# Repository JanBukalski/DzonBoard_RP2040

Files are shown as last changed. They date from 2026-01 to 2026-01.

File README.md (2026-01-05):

# DzonBoard

MCU based on RP2040 microcontroller.
Pin Layout is Equal to Raspberry Pi Pico Pin Layout.

# Why devboard

I made it becouse i think it is fun. And i wanted to learn KiCad.

Now i made working PCB. Before i had 40 errors and now i have 0 :)

# Pictures

Pictures are in pics/ folder.
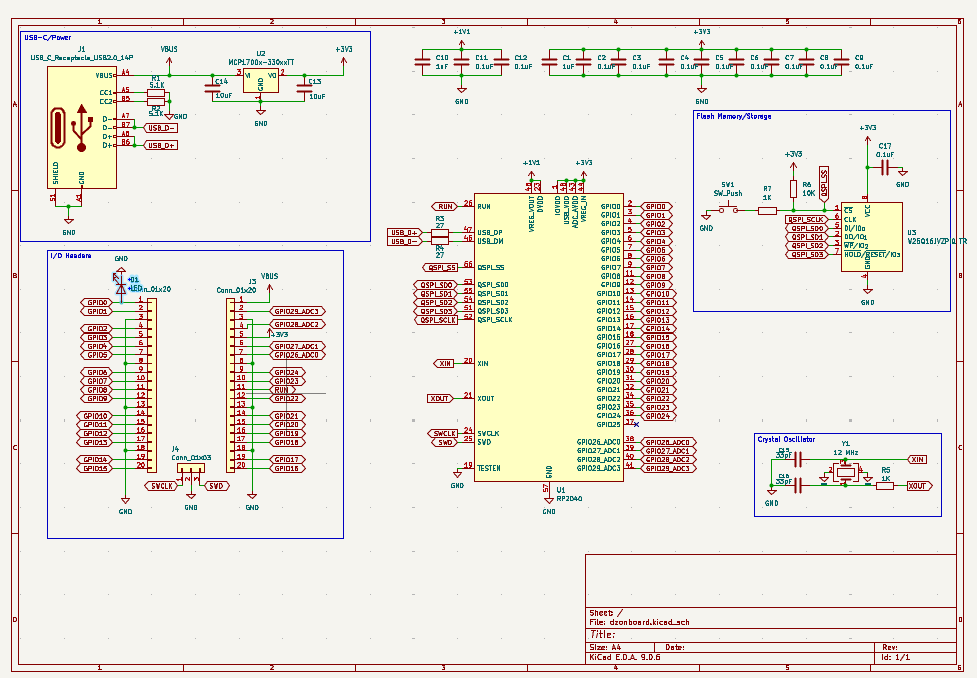
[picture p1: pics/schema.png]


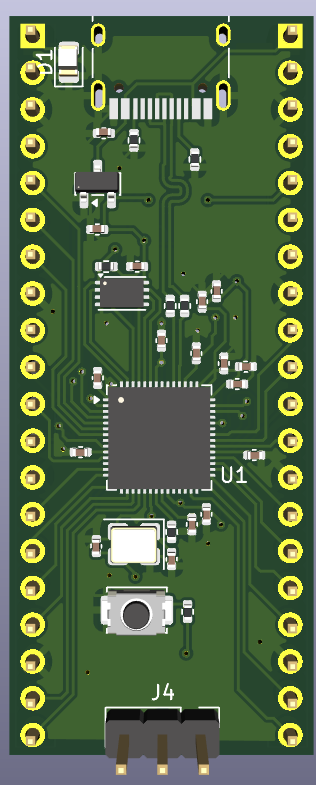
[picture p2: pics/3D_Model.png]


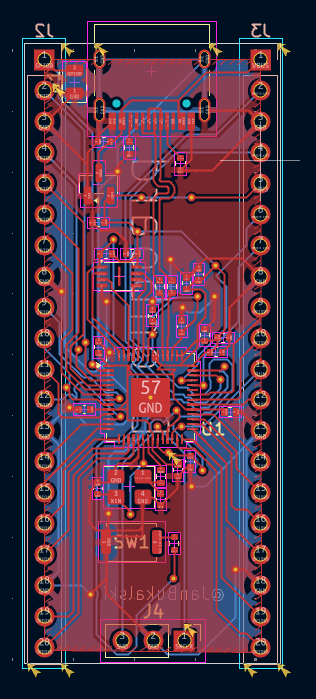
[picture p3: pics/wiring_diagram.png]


# BOM

BOM is in bom.csv file

# Example software

Example firmware is in examples/ folder..

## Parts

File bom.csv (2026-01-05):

Designator | Footprint | Quantity | Value | LCSC Part # | Total price
C1, C10 | 0402 | 2 | 1uF | C15525 | $0.0060
C11, C12, C17, C2, C3, C4, C5, C6, C7, C8, C9 | 0402 | 11 | 0.1uF | C1525 | $0.0132
C13, C14 | 0402 | 2 | 10uF | C15533 | $0.0088
C15, C16 | 0402 | 2 | 33pF | C15515 | $0.0022
D1 | 0805 | 1 | LED | C2290 | $0.0121
J1 | USB_C_Receptacle_HRO_TYPE-C-31-M-12 | 1 | USB_C_Receptacle_USB2.0_14P | C165948 | $0.1764
J2, J3 | PinHeader_1x20_P2.54mm_Vertical | 2 | Conn_01x20 | C124356 | Buying in diffrent shop
J4 | PinHeader_1x03_P2.54mm_Vertical | 1 | Conn_01x03 | C30030 | Buying in diffrent shop
R1, R2 | 0402 | 2 | 5.1K | C25124 | $0.0012
R3, R4 | 0402 | 2 | 27 | C25089 | $0.0012
R5, R7 | 0402 | 2 | 1K | C21190 | $0.0443
R6 | 0402 | 1 | 10K | C25744 | $0.0006
SW1 | SW_Push_SPST_NO_Alps_SKRK | 1 | SW_Push | C13974 | $0.0678
U1 | QFN-56-1EP_7x7mm_P0.4mm_EP3.2x3.2mm | 1 | RP2040 | C2040 | $0.9545
U2 | SOT-23 | 1 | MCP1700x-330xxTT | C13456 | $0.0443
U3 | Winbond_USON-8-1EP_3x2mm_P0.5mm_EP0.2x1.6mm | 1 | W25Q16JVZPIQ TR | C20123 | $0.9358
Y1 | Crystal_SMD_3225-4Pin_3.2x2.5mm | 1 | 12 MHz | C12345 | $0.0242

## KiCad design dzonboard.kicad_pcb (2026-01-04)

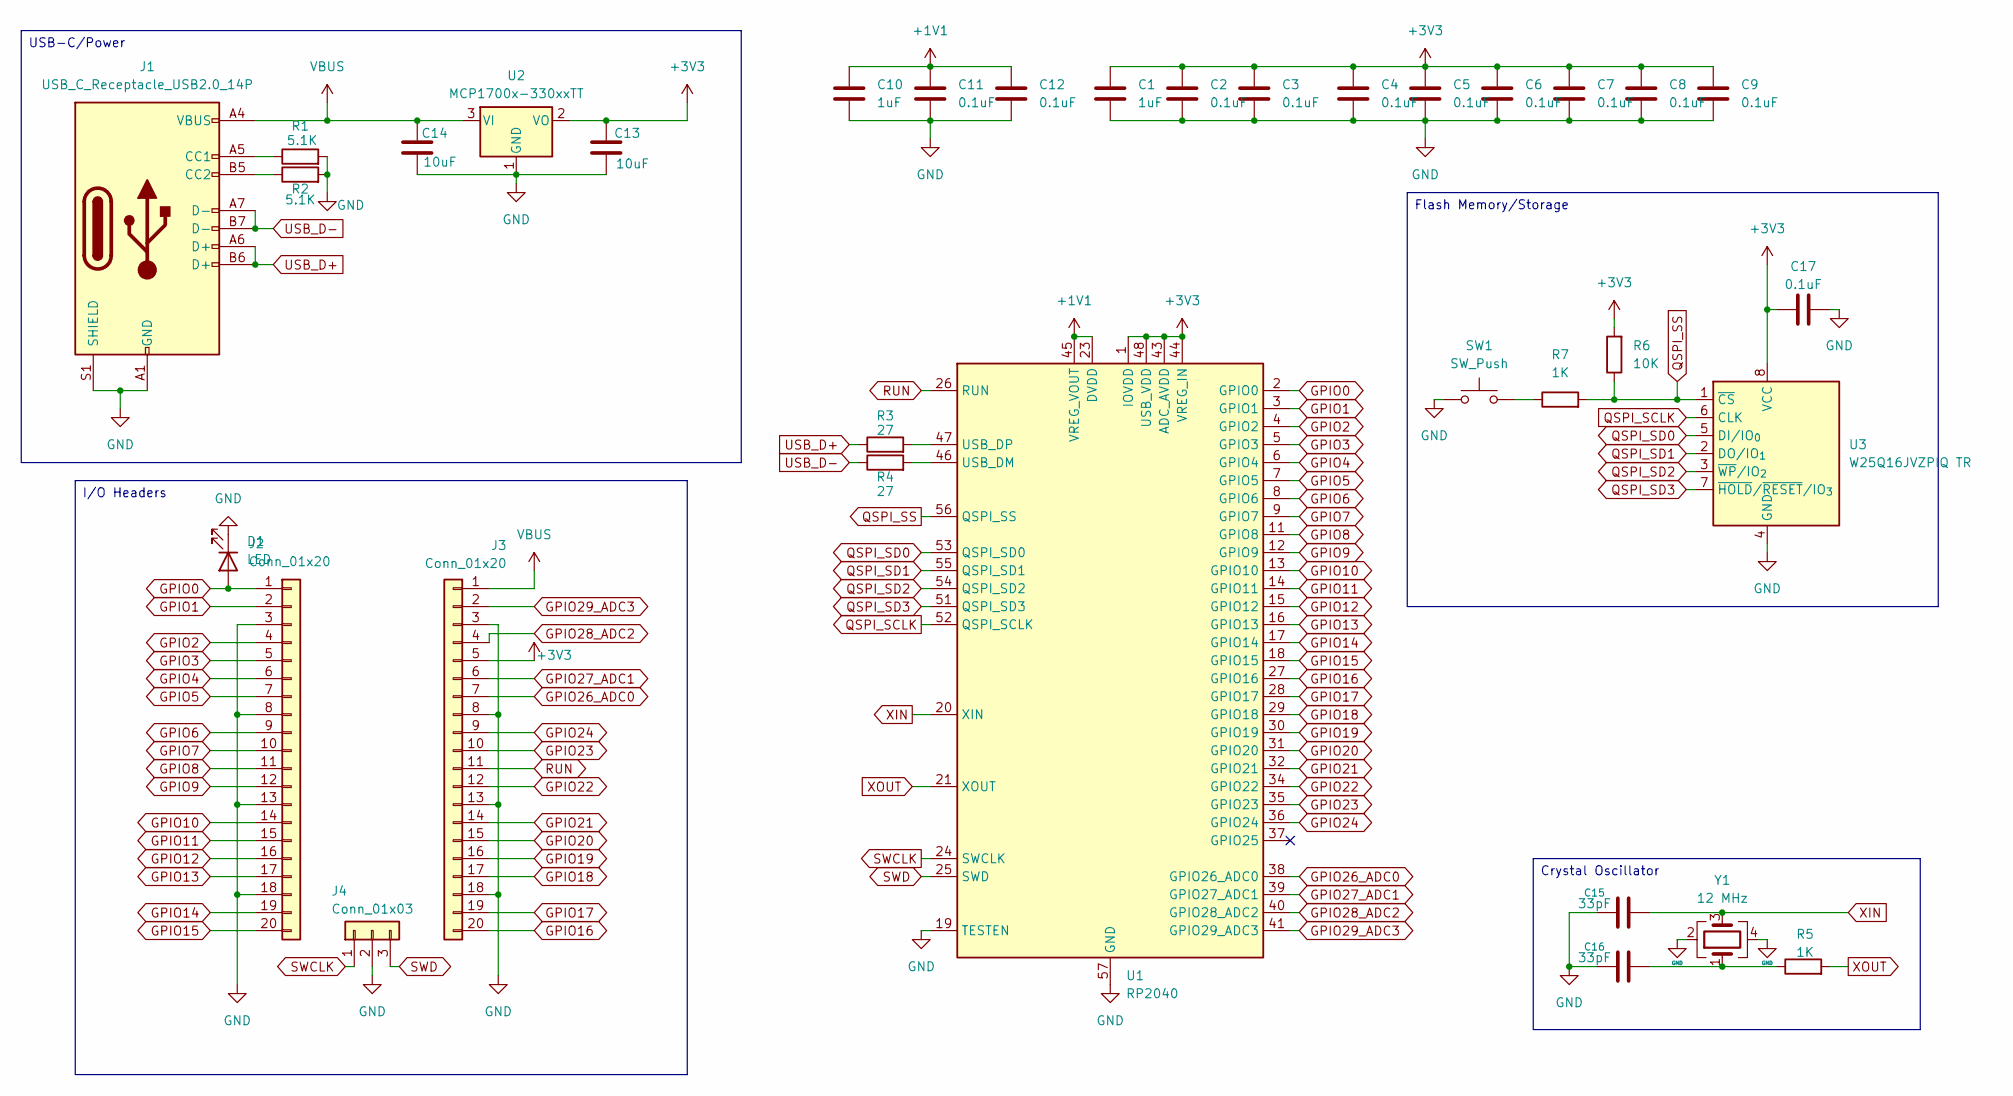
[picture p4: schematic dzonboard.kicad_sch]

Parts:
C1, C10: 1uF; C_0402_1005Metric
C2, C3, C4, C5, C6, C7, C8, C9, C11, C12, C17: 0.1uF; C_0402_1005Metric
C13, C14: 10uF; C_0402_1005Metric
C15, C16: 33pF; C_0402_1005Metric
D1: LED; LED_0805_2012Metric
J1: USB_C_Receptacle_USB2.0_14P; USB_C_Receptacle_HRO_TYPE-C-31-M-12
J2, J3: Conn_01x20; PinHeader_1x20_P2.54mm_Vertical
J4: Conn_01x03; PinHeader_1x03_P2.54mm_Vertical
R1, R2: 5.1K; R_0402_1005Metric
R3, R4: 27; R_0402_1005Metric
R5, R7: 1K; R_0402_1005Metric
R6: 10K; R_0402_1005Metric
SW1: SW_Push; SW_Push_SPST_NO_Alps_SKRK
U1: RP2040; QFN-56-1EP_7x7mm_P0.4mm_EP3.2x3.2mm
U2: MCP1700x-330xxTT; SOT-23
U3: W25Q16JVZPIQ TR; Winbond_USON-8-1EP_3x2mm_P0.5mm_EP0.2x1.6mm
Y1: 12 MHz; Crystal_SMD_3225-4Pin_3.2x2.5mm

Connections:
+1V1: C10.1, C11.1, C12.1, U1.23 (DVDD), U1.45 (VREG_VOUT), U1.50 (DVDD)
+3V3: C1.1, C2.1, C3.1, C4.1, C5.1, C6.1, C7.1, C8.1, C9.1, C13.1, C17.1, J3.5, R6.2, U1.1 (IOVDD), U1.10 (IOVDD), U1.22 (IOVDD), U1.33 (IOVDD), U1.42 (IOVDD), U1.43 (ADC_AVDD), U1.44 (VREG_IN), U1.48 (USB_VDD), U1.49 (IOVDD), U2.2 (VO), U3.8 (VCC)
GND: C1.2, C2.2, C3.2, C4.2, C5.2, C6.2, C7.2, C8.2, C9.2, C10.2, C11.2, C12.2, C13.2, C14.2, C15.1, C16.1, C17.2, D1.1 (K), J1.A1 (GND), J1.A12 (GND), J1.B1 (GND), J1.B12 (GND), J1.S1 (SHIELD), J2.3, J2.8, J2.13, J2.18, J3.3, J3.8, J3.13, J3.18, J4.2, R1.2, R2.2, SW1.1, U1.19 (TESTEN), U1.57 (GND), U2.1 (GND), U3.4 (GND), Y1.2, Y1.4
GPIO0: D1.2 (A), J2.1, U1.2 (GPIO0)
GPIO1: J2.2, U1.3 (GPIO1)
GPIO2: J2.4, U1.4 (GPIO2)
GPIO3: J2.5, U1.5 (GPIO3)
GPIO4: J2.6, U1.6 (GPIO4)
GPIO5: J2.7, U1.7 (GPIO5)
GPIO6: J2.9, U1.8 (GPIO6)
GPIO7: J2.10, U1.9 (GPIO7)
GPIO8: J2.11, U1.11 (GPIO8)
GPIO9: J2.12, U1.12 (GPIO9)
GPIO10: J2.14, U1.13 (GPIO10)
GPIO11: J2.15, U1.14 (GPIO11)
GPIO12: J2.16, U1.15 (GPIO12)
GPIO13: J2.17, U1.16 (GPIO13)
GPIO14: J2.19, U1.17 (GPIO14)
GPIO15: J2.20, U1.18 (GPIO15)
GPIO16: J3.20, U1.27 (GPIO16)
GPIO17: J3.19, U1.28 (GPIO17)
GPIO18: J3.17, U1.29 (GPIO18)
GPIO19: J3.16, U1.30 (GPIO19)
GPIO20: J3.15, U1.31 (GPIO20)
GPIO21: J3.14, U1.32 (GPIO21)
GPIO22: J3.12, U1.34 (GPIO22)
GPIO23: J3.10, U1.35 (GPIO23)
GPIO24: J3.9, U1.36 (GPIO24)
GPIO26_ADC0: J3.7, U1.38 (GPIO26_ADC0)
GPIO27_ADC1: J3.6, U1.39 (GPIO27_ADC1)
GPIO28_ADC2: J3.4, U1.40 (GPIO28_ADC2)
GPIO29_ADC3: J3.2, U1.41 (GPIO29_ADC3)
unnamed: C16.2, R5.1, Y1.1
unnamed: J1.A5 (CC1), R1.1
unnamed: J1.B5 (CC2), R2.1
unnamed: R7.1, SW1.2
unnamed: R4.2, U1.46 (USB_DM)
unnamed: R3.2, U1.47 (USB_DP)
QSPI_SCLK: U1.52 (QSPI_SCLK), U3.6 (CLK)
QSPI_SD0: U1.53 (QSPI_SD0), U3.5 (DI/IO_{0})
QSPI_SD1: U1.55 (QSPI_SD1), U3.2 (DO/IO_{1})
QSPI_SD2: U1.54 (QSPI_SD2), U3.3 (~WP/IO_{2})
QSPI_SD3: U1.51 (QSPI_SD3), U3.7 (~HOLD/~RESET/IO_{3})
QSPI_SS: R6.1, R7.2, U1.56 (QSPI_SS), U3.1 (~CS)
RUN: J3.11, U1.26 (RUN)
SWCLK: J4.1, U1.24 (SWCLK)
SWD: J4.3, U1.25 (SWD)
USB_D+: J1.A6 (D+), J1.B6 (D+), R3.1
USB_D-: J1.A7 (D-), J1.B7 (D-), R4.1
VBUS: C14.1, J1.A4 (VBUS), J1.A9 (VBUS), J1.B4 (VBUS), J1.B9 (VBUS), J3.1, U2.3 (VI)
XIN: C15.2, U1.20 (XIN), Y1.3
XOUT: R5.2, U1.21 (XOUT)

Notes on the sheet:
I/O Headers
Flash Memory/Storage
USB-C/Power
Crystal Oscillator

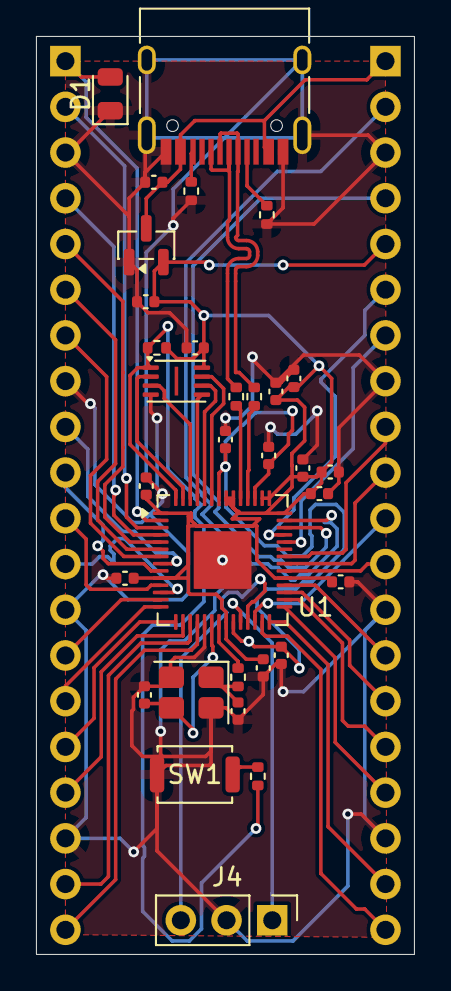
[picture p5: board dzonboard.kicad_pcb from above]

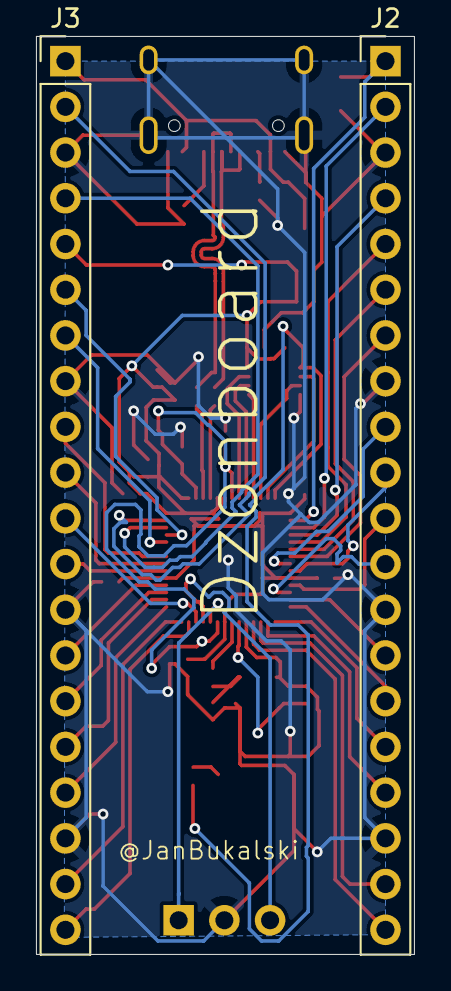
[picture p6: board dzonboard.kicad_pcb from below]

Board: 2 copper layers, 21.0 x 51.0 mm, 34 parts (2 on the bottom side), 52 nets.

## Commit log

2026-01-05 updated BOM
    [bom.csv]
2026-01-05 Update column name from 'Comment' to 'Designation'
    [bom.csv]
2026-01-05 Revise BOM structure and add new fields
    Updated the BOM format to include new columns for Value and LCSC Part #.
    [bom.csv]
2026-01-05 Update bom.csv to include total price and notes
    [bom.csv]
